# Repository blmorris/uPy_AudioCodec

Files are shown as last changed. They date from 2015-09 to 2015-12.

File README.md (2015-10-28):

# uPy_AudioCodec

The uPy_AudioCodec is a daughterboard for the [MicroPython pyboard](http://micropython.org)
containing:
* The SSM2604 I2S audio codec chip from Analog Devices: [Webpage](http://www.analog.com/en/products/audio-video/audio-amplifiers/ssm2604.html), [Datasheet](http://www.analog.com/media/en/technical-documentation/data-sheets/SSM2604.pdf)
* The TPA6130A2 headphone amplifer from Texas Instruments: [Webpage](http://www.ti.com/product/TPA6130A2), [Datasheet](http://www.ti.com/lit/ds/symlink/tpa6130a2.pdf)

This repository contains the design files for the board along with
code to use it with MicroPython.

# Quick Start

To use the uPy_AudioCodec you will need the following:
* A MicroPython pyboard
* The codec board along with the optional microphone plug
* A 16-bit stereo *.wav file encoded at either 44.1kHz (CD-quality) or 48kHz
  sample rate. (Other sample rates are theoretically supported but
  untested so far.)

* A micro-SD card (to store the *.wav file)
* A pair of headphones or earbuds with 3.5mm (1/8") stereo plug

Assemble the daughterboard in the pyboard with the microphone plug and
headphone plugged in as shown in the picture. Note that the
daughterboard must occupy the 'Y' position in the pyboard, as the SPI
port in the 'X' position (SPI1) does not support I2S.

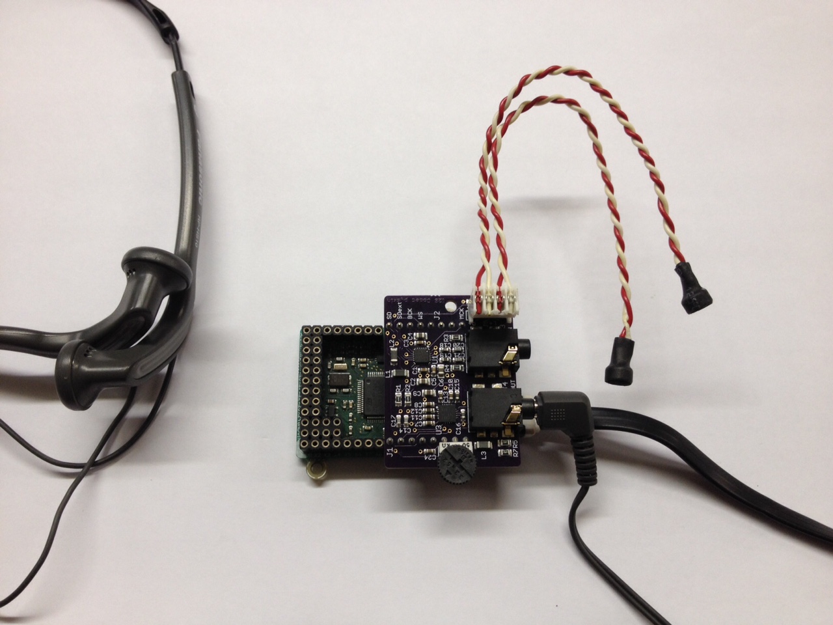
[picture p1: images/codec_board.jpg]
codec daughterboard in pyboard


Use DFU to load I2S supporting uPy firmware to pyboard:
[prebuilt firmware image in firmware/i2s-firmware.dfu](firmware/i2s-firmware.dfu)

Until I2S support is merged into master at http://github.com/micropython/micropython I will occasionally update the I2S firmware image to track my [micropython i2s branch](https://github.com/blmorris/micropython/tree/i2s)

The following code is a very quick-and-dirty way to initialize the
AudioCodec board in python - I will clean this up soon!:

```Python
import pyb
pot = pyb.ADC('Y12')
hpctl = pyb.Pin('Y11')
hpctl.init(hpctl.OUT_PP)
hpctl.high()
i2c = pyb.I2C(2)
i2c.init(i2c.MASTER)
# Might do a 'try' here to make sure both i2c devices are working:
i2c.scan()
# Should give [26, 96]

# Set Headphone Amp chip registers:
i2c.mem_write(0xc0, 96, 1) # control register: enable both amplifier channels, activate stereo mode
i2c.mem_write(0x35, 96, 2) # volume register; unmute both channels, set gain to ~0dB
i2c.mem_write(0x00, 96, 3) # output tri-state register; set both channels to output mode

# Set codec registers:
# THe SSM2604 uses a register addressing scheme that does not map directly to the uPy
# mem_read / mem_write methods.
# There are a total of 11 9-bit registers (R0-R9 and R15) which are selected using a
# 7-bit address. Register writes are constructed using the 'send' method:
# i2c.send('0b<7-bit register address><9-bit register data>', 26)
# Register reads can use 'mem_read' but the register address must be multiplied by 2
# (or shifted 1 bit left, so the 7-bit address is left justified)
# The read should be for two bytes, and the 'bytes' object that is returned will be
# two bytes long with the LSB first

# Set up Codec for Pass-Through
i2c.send(b'\x00\x17', 26) # LEFT ADC INPUT GAIN, ADDRESS 0x00: unmute left ADC, input gain=0dB
i2c.send(b'\x02\x17', 26) # RIGHT ADC INPUT GAIN, ADDRESS 0x01: unmute right ADC, input gain=0dB
# R2 and R3 are reserved
i2c.send(b'\x08\x08', 26) # ANALOG AUDIO PATH, ADDRESS 0x04: Bypass select, DAC not selected
i2c.send(b'\x0a\x08', 26) # DIGITAL AUDIO PATH, ADDRESS 0x05: leave default, DAC is muted
i2c.send(b'\x0c\x7e', 26) # POWER MANAGEMENT, ADDRESS 0x06: power on chip and line-in
#i2c.send(b'\x0e\x0a', 26) # DIGITAL AUDIO I/F, ADDRESS 0x07: I2S parameters, leave default
i2c.send(b'\x0e\x02', 26) # DIGITAL AUDIO I/F, ADDRESS 0x07: Set 16-bit, I2S mode
i2c.send(b'\x10\x00', 26) # SAMPLING RATE, ADDRESS 0x08: leave default

# Set up Codec for DAC playback:
i2c.send(b'\x08\x10', 26)
i2c.send(b'\x0a\x00', 26)
i2c.send(b'\x0c\x72', 26)
i2c.send(b'\x0e\x02', 26)
i2c.send(b'\x10\x00', 26)
i2c.send(b'\x12\x01', 26)

tim = pyb.Timer(1, freq=20)
def set_volume(tim, buf=bytearray(1)):
    buf[0] = pot.read() >> 6
    i2c.mem_write(buf, 96, 2)

tim.callback(set_volume)

i2s = pyb.I2S()
i2s.init(i2s.MASTER, mclkout=1)
i2s.stream_out(f)

def test_stream():
    i2c.send(b'\x00\x17', 26) # LEFT IN GAIN = 0dB
    i2c.send(b'\x02\x17', 26) # RIGHT IN GAIN = 0dB
    i2c.send(b'\x08\x10', 26)

def test_mic():
    i2c.send(b'\x00\x27', 26) # LEFT IN GAIN = +24dB
    i2c.send(b'\x02\x27', 26) # RIGHT IN GAIN = +24dB
    i2c.send(b'\x08\x08', 26)

```

Then the following to start streaming out to your headphones:

```Python
f = open('/path/to/wave/file', 'rb')
f.seek(44) # to skip past wave file header
i2s.stream_out(f)
```

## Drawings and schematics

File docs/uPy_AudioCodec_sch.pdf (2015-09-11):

### ABCDE

### ABCDE

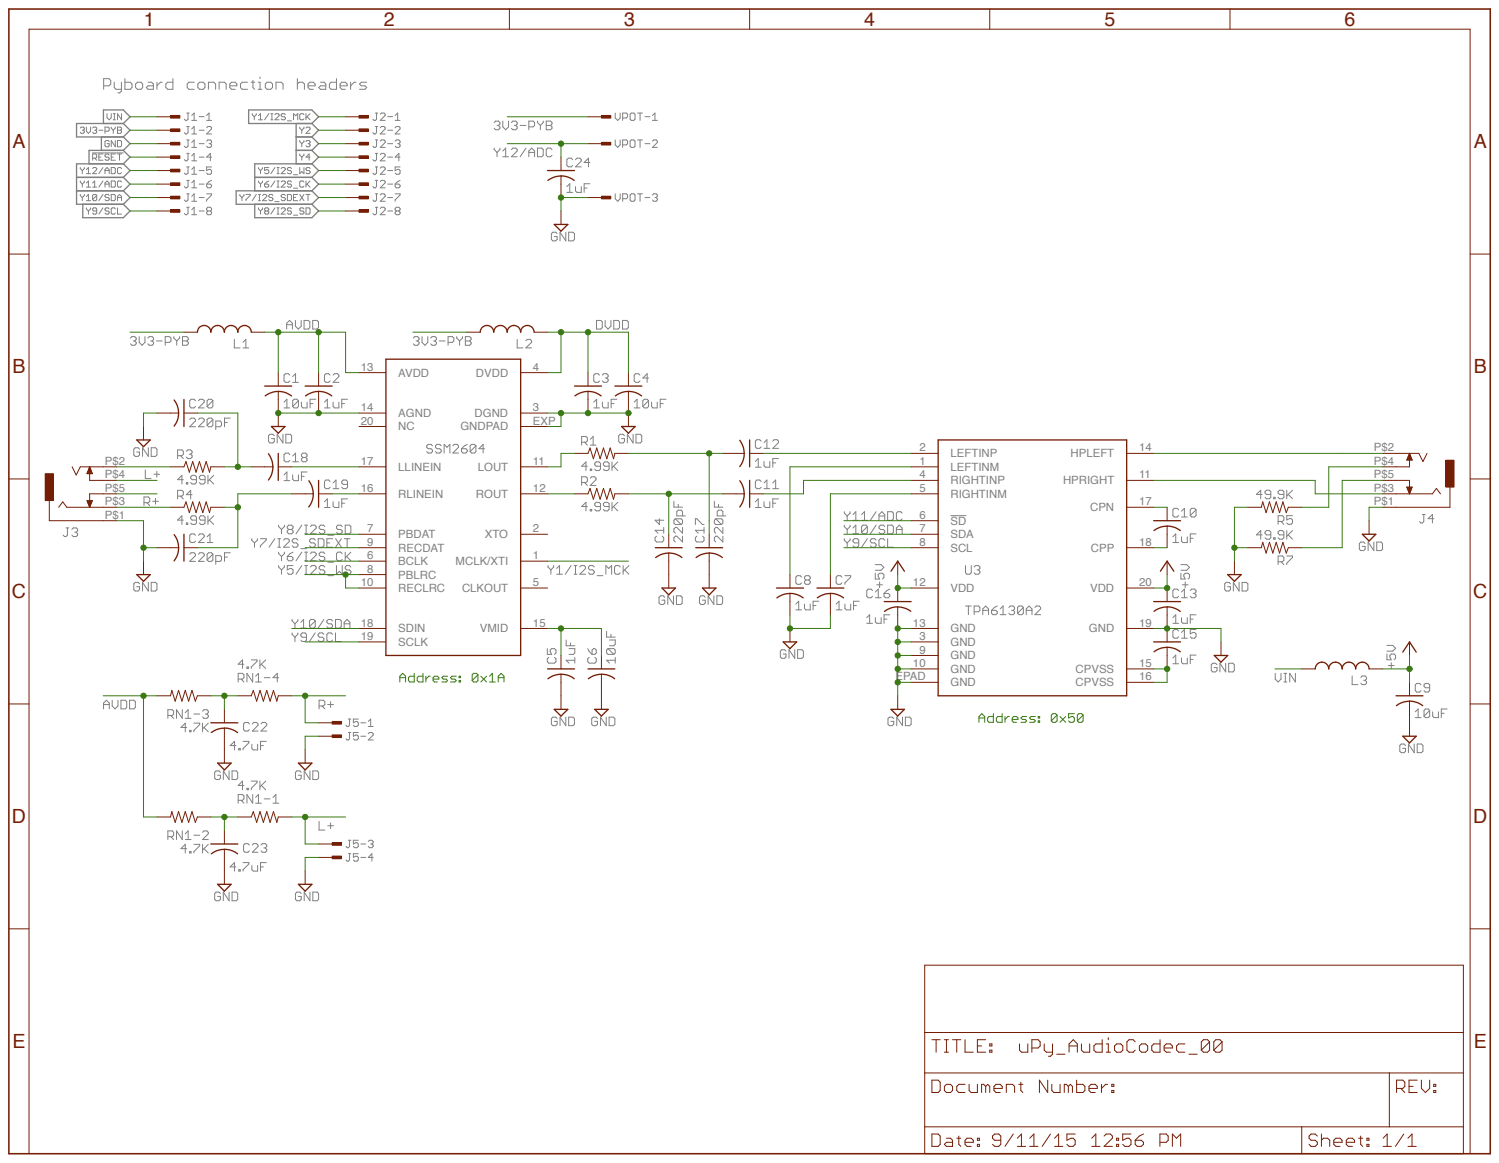
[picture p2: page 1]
P$5 LEFTINM; LEFTINP 2; GND; RIGHTINP; RIGHTINM; SDA; SCL; 9 GND 10; HPRIGHT; VDD 12; GND 13; HPLEFT; CPVSS; CPN; CPP; VDD; GND EPAD; SDIN 18; RLINEIN 16; LLINEIN 17; AVDD 13; AGND 14; DVDD; DGND; MCLK/XTI; XTO; BCLK; PBLRC; 8 RECLRC 10; SCLK 19; CLKOUT; LOUT; ROUT; VMID; PBDAT; RECDAT; GNDPAD; EXP

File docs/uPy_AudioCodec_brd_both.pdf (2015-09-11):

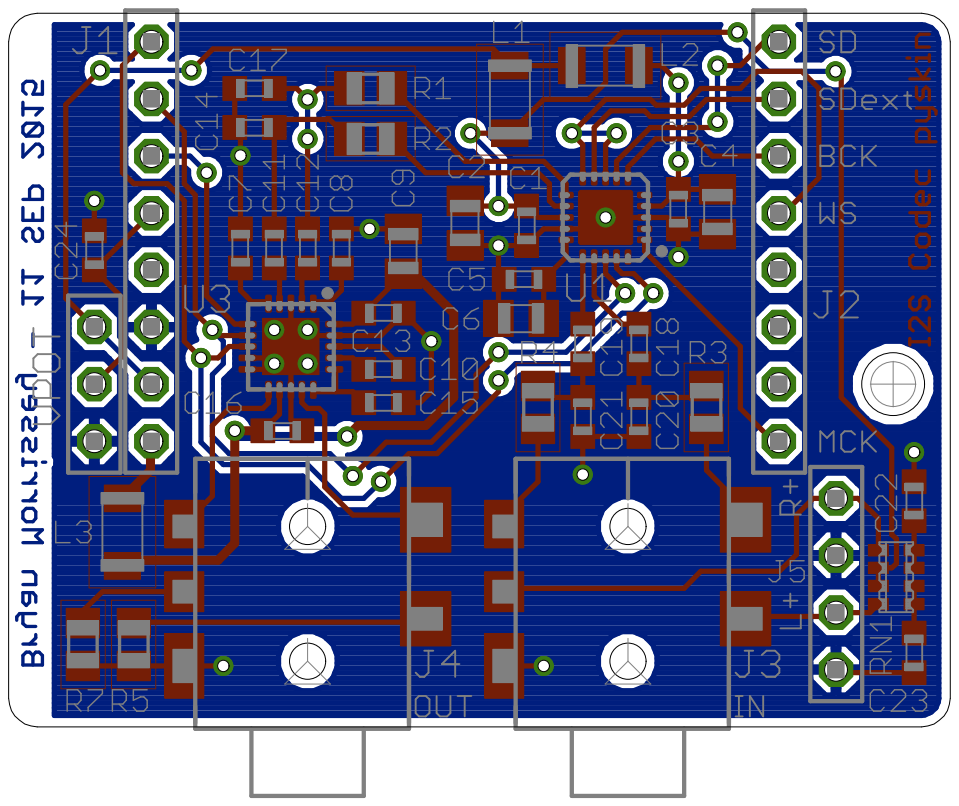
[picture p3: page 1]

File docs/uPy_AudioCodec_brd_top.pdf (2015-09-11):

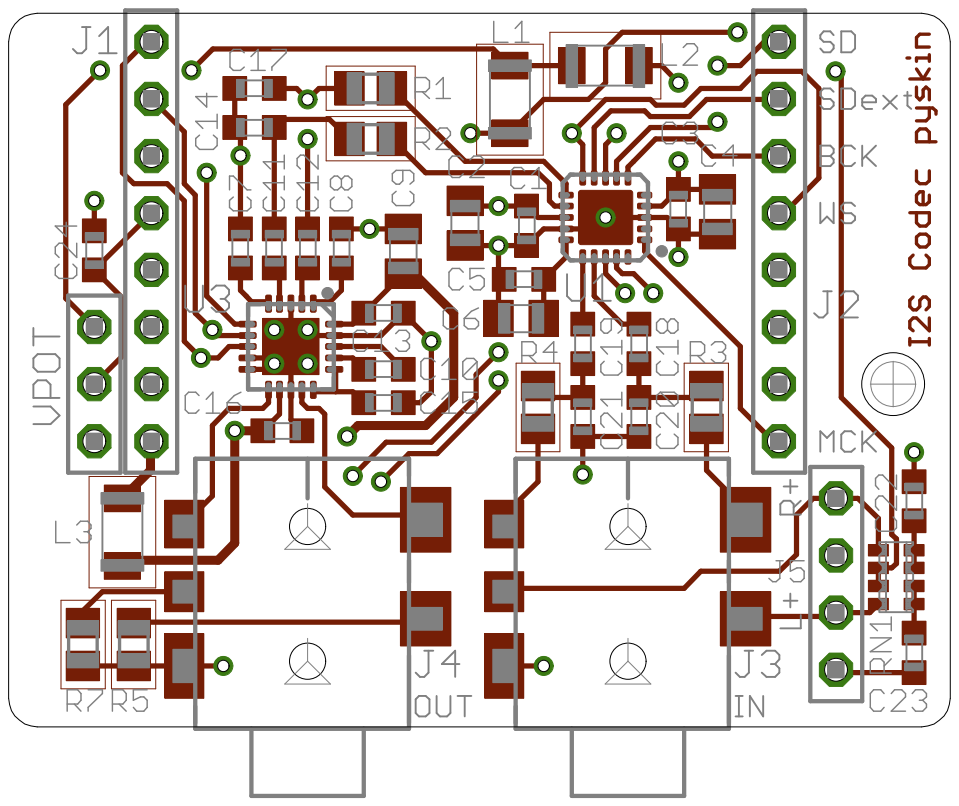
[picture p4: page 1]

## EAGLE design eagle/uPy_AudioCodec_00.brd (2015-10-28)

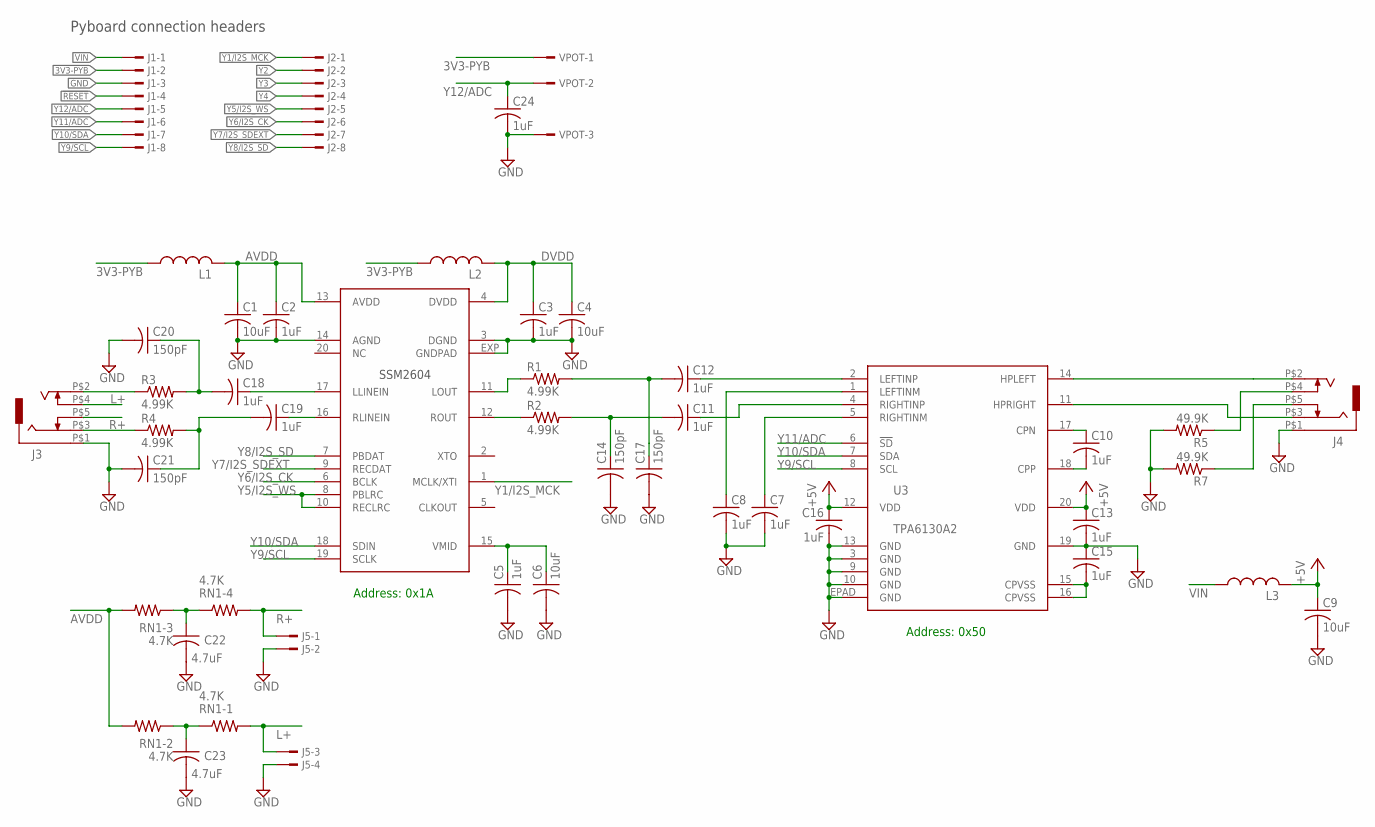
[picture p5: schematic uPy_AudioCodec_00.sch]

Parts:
C1: 10uF; C0603K
C2: 1uF; C0805K
C3, C5, C7, C8, C10, C11, C12, C13, C15, C16, C18, C19, C24: 1uF; C0603K
C4, C6, C9: 10uF; C0805K
C14, C17, C20, C21: 150pF; C0603K
C22, C23: 4.7uF; C0603K
J1, J2: TSW-108-02-S-S-MOD
J3, J4: CON-JACK-STEREO; CON-JACK-SJ1-3515-SMT
J5: TSW-104-02-S-S; TSW-104-02-S-S-MOD
L1, L2, L3: L-USL3216C; L3216C
R1, R2, R3, R4: 4.99K; R0805
R5, R7: 49.9K; R0805
RN1: 4.7K; CTS-742C083+
U1: SSM2604-1; LFCSP20-1
U3: TPA6130A2; QFN20-EP
VPOT: TSW-103-02-S-S; TSW-103-02-S-S-MOD

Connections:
3V3-PYB: J1.2, L1.1, L2.1, VPOT.1
!RESET: J1.4
+5V: C9.1, C13.1, C16.1, L3.2, U3.12 (VDD), U3.20 (VDD)
AVDD: C1.1, C2.1, L1.2, RN1.P$6 (2), RN1.P$7 (2), U1.13 (AVDD)
DVDD: C3.1, C4.1, L2.2, U1.4 (DVDD)
GND: C1.2, C2.2, C3.2, C4.2, C5.2, C6.2, C7.2, C8.2, C9.2, C13.2, C14.2, C15.1, C16.2, C17.2, C20.2, C21.2, C22.2, C23.2, C24.2, J1.3, J3.P$1 (SLEEVE), J4.P$1 (SLEEVE), J5.2, J5.4, R5.2, R7.2, U1.3 (DGND), U1.14 (AGND), U1.EXP (GNDPAD), U3.3 (GND), U3.9 (GND), U3.10 (GND), U3.13 (GND), U3.19 (GND), U3.EPAD (GND), VPOT.3
L+: J3.P$4 (TIP_SW), J5.3, RN1.P$8 (2)
unnamed: C12.1, U3.2 (LEFTINP)
unnamed: C18.1, U1.17 (LLINEIN)
unnamed: C19.1, U1.16 (RLINEIN)
unnamed: C11.1, U3.4 (RIGHTINP)
unnamed: J4.P$2 (TIP), U3.14 (HPLEFT)
unnamed: C5.1, C6.1, U1.15 (VMID)
unnamed: C7.1, U3.5 (RIGHTINM)
unnamed: C8.1, U3.1 (LEFTINM)
unnamed: R1.1, U1.11 (LOUT)
unnamed: C15.2, U3.15 (CPVSS), U3.16 (CPVSS)
unnamed: C10.2, U3.18 (CPP)
unnamed: J4.P$3 (RING), U3.11 (HPRIGHT)
unnamed: C10.1, U3.17 (CPN)
unnamed: R2.1, U1.12 (ROUT)
unnamed: C11.2, C14.1, R2.2
unnamed: J4.P$5 (RING_SW), R7.1
unnamed: J4.P$4 (TIP_SW), R5.1
unnamed: C12.2, C17.1, R1.2
unnamed: J3.P$3 (RING), R4.1
unnamed: J3.P$2 (TIP), R3.1
unnamed: C18.2, C20.1, R3.2
unnamed: C19.2, C21.1, R4.2
unnamed: C22.1, RN1.P$3 (1), RN1.P$4 (1)
unnamed: C23.1, RN1.P$1 (1), RN1.P$2 (1)
R+: J3.P$5 (RING_SW), J5.1, RN1.P$5 (2)
VIN: J1.1, L3.1
Y1/I2S_MCK: J2.1, U1.1 (MCLK/XTI)
Y2: J2.2
Y3: J2.3
Y4: J2.4
Y5/I2S_WS: J2.5, U1.8 (PBLRC), U1.10 (RECLRC)
Y6/I2S_CK: J2.6, U1.6 (BCLK)
Y7/I2S_SDEXT: J2.7, U1.9 (RECDAT)
Y8/I2S_SD: J2.8, U1.7 (PBDAT)
Y9/SCL: J1.8, U1.19 (SCLK), U3.8 (SCL)
Y10/SDA: J1.7, U1.18 (SDIN), U3.7 (SDA)
Y11/ADC: J1.6, U3.6 (!SD)
Y12/ADC: C24.1, J1.5, VPOT.2

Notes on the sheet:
Pyboard connection headers
Address: 0x50
SSM2604
Address: 0x1A

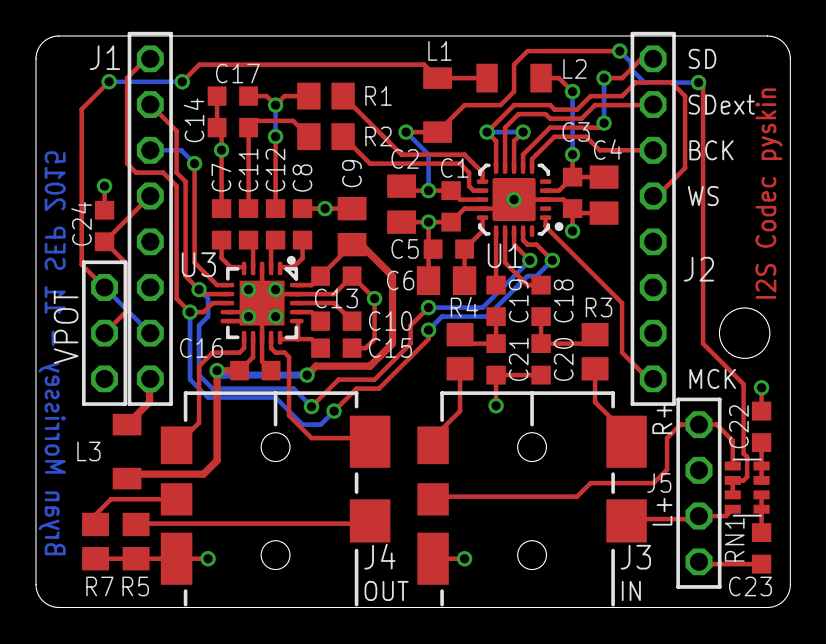
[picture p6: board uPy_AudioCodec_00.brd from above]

Board: 2 copper layers, 41.9 x 31.8 mm, 42 parts (0 on the bottom side), 41 nets.

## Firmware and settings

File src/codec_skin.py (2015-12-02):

import pyb
pot = pyb.ADC('Y12')
hpctl = pyb.Pin('Y11')
hpctl.init(hpctl.OUT_PP)
hpctl.high()
i2c = pyb.I2C(2)
i2c.init(i2c.MASTER)
# Might do a 'try' here to make sure both i2c devices are working:
i2c.scan()
#> [26, 96]

# Set Headphone Amp chip registers:
i2c.mem_write(0xc0, 96, 1) # control register: enable both amplifier channels, activate stereo mode
i2c.mem_write(0x35, 96, 2) # volume register; unmute both channels, set gain to ~0dB
i2c.mem_write(0x00, 96, 3) # output tri-state register; set both channels to output mode

# Set codec registers:
# THe SSM2604 uses a register addressing scheme that does not map directly to the uPy
# mem_read / mem_write methods.
# There are a total of 11 9-bit registers (R0-R9 and R15) which are selected using a
# 7-bit address. Register writes are constructed using the 'send' method:
# i2c.send('0b<7-bit register address><9-bit register data>', 26)
# Register reads can use 'mem_read' but the register address must be multiplied by 2
# (or shifted 1 bit left, so the 7-bit address is left justified)
# The read should be for two bytes, and the 'bytes' object that is returned will be
# two bytes long with the LSB first

# Set up Codec for Pass-Through
i2c.send(b'\x00\x17', 26) # LEFT ADC INPUT GAIN, ADDRESS 0x00: unmute left ADC, input gain=0dB
i2c.send(b'\x02\x17', 26) # RIGHT ADC INPUT GAIN, ADDRESS 0x01: unmute right ADC, input gain=0dB
# R2 and R3 are reserved
i2c.send(b'\x08\x08', 26) # ANALOG AUDIO PATH, ADDRESS 0x04: Bypass select, DAC not selected
i2c.send(b'\x0a\x08', 26) # DIGITAL AUDIO PATH, ADDRESS 0x05: leave default, DAC is muted
i2c.send(b'\x0c\x7e', 26) # POWER MANAGEMENT, ADDRESS 0x06: power on chip and line-in
#i2c.send(b'\x0e\x0a', 26) # DIGITAL AUDIO I/F, ADDRESS 0x07: I2S parameters, leave default
i2c.send(b'\x0e\x02', 26) # DIGITAL AUDIO I/F, ADDRESS 0x07: Set 16-bit, I2S mode
i2c.send(b'\x10\x00', 26) # SAMPLING RATE, ADDRESS 0x08: leave default

# Set up Codec for DAC playback:
i2c.send(b'\x08\x10', 26)
i2c.send(b'\x0a\x00', 26)
i2c.send(b'\x0c\x72', 26)
i2c.send(b'\x0e\x02', 26)
i2c.send(b'\x10\x00', 26)
i2c.send(b'\x12\x01', 26)

# tim = pyb.Timer
# def set_volume(tim, buf=bytearray(3)):
#     val = pot.read()
#     buf[0] = val
#     buf[1] = val >> 8
#     i2c.mem_write(buf, 0x32, 0, addr_size=16)
# tim.callback(set_volume)

tim = pyb.Timer(1, freq=20)
def set_volume(tim, buf=bytearray(1)):
    buf[0] = pot.read() >> 6
    i2c.mem_write(buf, 96, 2)
    

tim.callback(set_volume)

i2s = pyb.I2S()
i2s.init(i2s.MASTER, mclkout=1)
f = open('/sd/5_15-48kHz.wav', 'rb')
i2s.stream_out(f)

def test_stream():
    i2c.send(b'\x00\x17', 26) # LEFT IN GAIN = 0dB
    i2c.send(b'\x02\x17', 26) # RIGHT IN GAIN = 0dB
    i2c.send(b'\x08\x10', 26)

def test_mic():
    i2c.send(b'\x00\x27', 26) # LEFT IN GAIN = +24dB
    i2c.send(b'\x02\x27', 26) # RIGHT IN GAIN = +24dB
    i2c.send(b'\x08\x08', 26)



#
import codec
>>> codec.i2s.deinit()
>>> i2s = pyb.I2S()
>>> i2s.init(i2s.MASTER, mclkout=1)
>>> i2s.send_recv(b'0123456789abcdef')
Traceback (most recent call last):
  File "<stdin>", line 1, in <module>
OSError: 116
>>> i2s.init(i2s.MASTER, mclkout=1)
>>> i2s.send_recv(b'0123456789abcdef')
b'\xf5\xff\xfc\xff\xfc\xff\x02\x00\x06\x00\x12\x00\x08\x00\x02\x00'
>>> i2s.send_recv(b'0123456789abcdef')
b'\x0c\x00\r\x00\x11\x00\xfd\xff\r\x00\xf9\xff\x1b\x00\xe7\xff'
>>> i2s.send_recv(b'0123456789abcdef')
b"\x0c\x00\x08\x00#\x00\xf9\xff\xf3\xff'\x00#\x00\xf9\xff"
>>> i2s.send_recv(b'0123456789abcdef')
b'\xeb\xff1\x00F\x00\xbc\xff\xcc\xff[\x00\x88\x00\n\xff'
>>> i2s.send_recv(b'0123456789abcdef')
b'\xd5\xfe\x94\xfb\x1c\xfb\xfb\x00\x12\x01\t\xff\r\xffK\x01'
>>> i2s.send_recv(b'0123456789abcdef')
b')\x01.\x04\x11\x03o\xff\xac\xff\xd7\xff\xb3\xff[\x00'
>>> i2s.send_recv(b'0123456789abcdef')
b's\x00\xcd\x03l\x02\t\xff\xc0\xff\\\x00\x9e\xff\xe9\xfe'
>>> i2s.send_recv(b'0123456789abcdef')
b'\xba\x00H\xfc\n\x04^\x00f\xffn\xff\xc2\xff\x86\x00'
>>> i2s.send_recv(b'0123456789abcdef')
b'r\x00M\x03\xbe\x03/\xffR\xff@\x00\xd5\xff\xfb\xfe'
>>> i2s.send_recv(b'0123456789abcdef')
b']\x00<\xfcU\x03u\x00=\xff`\xff\xf0\xff\x9d\x00'
>>> i2s.send_recv(b'0123456789abcdef')
b'\x18\x00>\x032\x037\xff\x1e\xffI\x00\xac\x00\xf4\xfe'
>>> i2s.send_recv(b'0123456789abcdef')
b"\xab\xfe)\xfc\xd0\xfa}\x00\xdd\x00r\xff'\xff\x8f\x00"
>>> i2s.send_recv(b'0123456789abcdef')
b'?\x01?\x03\n\x05\xfb\xfe\xdc\xfez\x00\x9a\x00\x84\xfe'
>>> i2s.send_recv(b'0123456789abcdef')
b'\x9e\xfe\x9b\xfb*\xfb3\x00\xc0\x00\x03\x00J\xff\xfe\xfe'
>>> 



>>> import codec
>>> codec.i2s.deinit()
>>> i2s = pyb.I2S()
>>> i2s.init(i2s.MASTER, mclkout=1)
>>> b1 = bytearray(32)
>>> b2 = bytearray(32)
>>> i2s.send_recv(b1,b2)
Traceback (most recent call last):
  File "<stdin>", line 1, in <module>
OSError: 116
>>> i2s.init(i2s.MASTER, mclkout=1)
>>> i2s.send_recv(b1,b2)
bytearray(b"\x1b\x00\n\x00\x0f\x00\x04\x00 \x00'\x00\x01\x00\x05\x00\x12\x007\x00\xe6\xff\xf5\xff\x1c\x00;\x00\xd3\xff\xc1\xff")
>>> struct.unpack('h',b2[4:6])[0]
Traceback (most recent call last):
  File "<stdin>", line 1, in <module>
NameError: name 'struct' is not defined
>>> import struct
>>> struct.unpack('h',b2[4:6])[0]
15
>>> struct.unpack('h',b2[6:8])[0]
4


import os
os.listdir('/sd')
os.rmdir('/sd/test.wav')
import codec
codec.i2s.stop()
codec.i2c.send(b'\x00\x20', 26)
codec.i2c.send(b'\x02\x20', 26)
codec.i2c.send(b'\x0a\x06', 26)
f1 = open('/sd/test.wav', 'wb')
codec.i2s.stream_in(f1)
codec.i2s.stop()
f1.flush()
f1.close()
f1 = open('/sd/test.wav', 'rb')
codec.i2s.stream_out(f1)

codec.i2s.stop('stream_out')
codec.i2s.stop('stream_in')
codec.i2s.stop()


def cbk(self):
    print('Callback!')

codec.i2s.callback(cbk)

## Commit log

2015-09-11 Initial commit of uPy_AudioCodec Eagle project files
    [uPy_AudioCodec_00.brd, uPy_AudioCodec_00.sch]
2015-10-28 Directory reorganization: eagle files moved to eagle/, pdf files moved to docs/, add gerber files
    [uPy_AudioCodec_00.brd, uPy_AudioCodec_00.sch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]
2015-12-02 src: Add boot.py and codec.py source files and copy of current (broken) firmware: i2s-firmware_NW.dfu
    [codec.py, codec_skin.py]
